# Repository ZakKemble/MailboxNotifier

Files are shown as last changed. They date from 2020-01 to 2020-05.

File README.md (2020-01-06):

Remote Mail Notifier (and GPS tracker)
======================================

A notifier for when mail is received in your mail box! Uses an A9G GPRS/GPS module to send HTTP requests to a web server via the mobile network.\
A PHP script then sends messages to a Telegram group chat using the bot API. Since the A9G also has a built-in GPS receiver the mail notifier can be used as a GPS tracker!\
Also incorporates a BME280 environmental sensor and should last for around 4-5 years on a single charge of a 10440 lithium battery (~320mAh, equivalent AAA size), if mail is received 3 times per week.

[https://blog.zakkemble.net/remote-mail-notifier-and-gps-tracker/](https://blog.zakkemble.net/remote-mail-notifier-and-gps-tracker/)

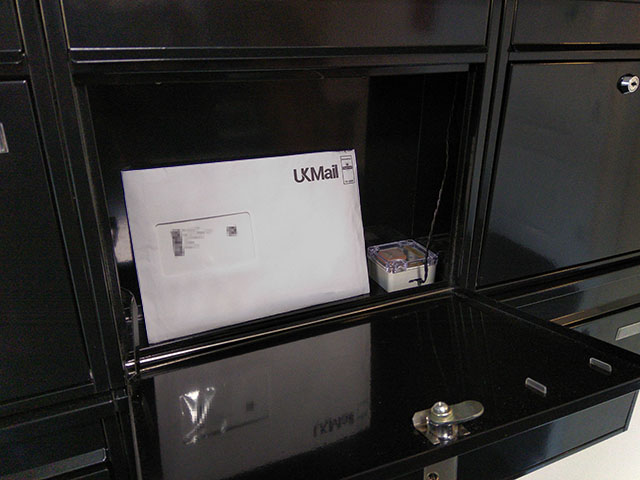
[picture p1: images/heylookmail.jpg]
Mail notifier pic


--------

Zak Kemble

contact@zakkemble.net

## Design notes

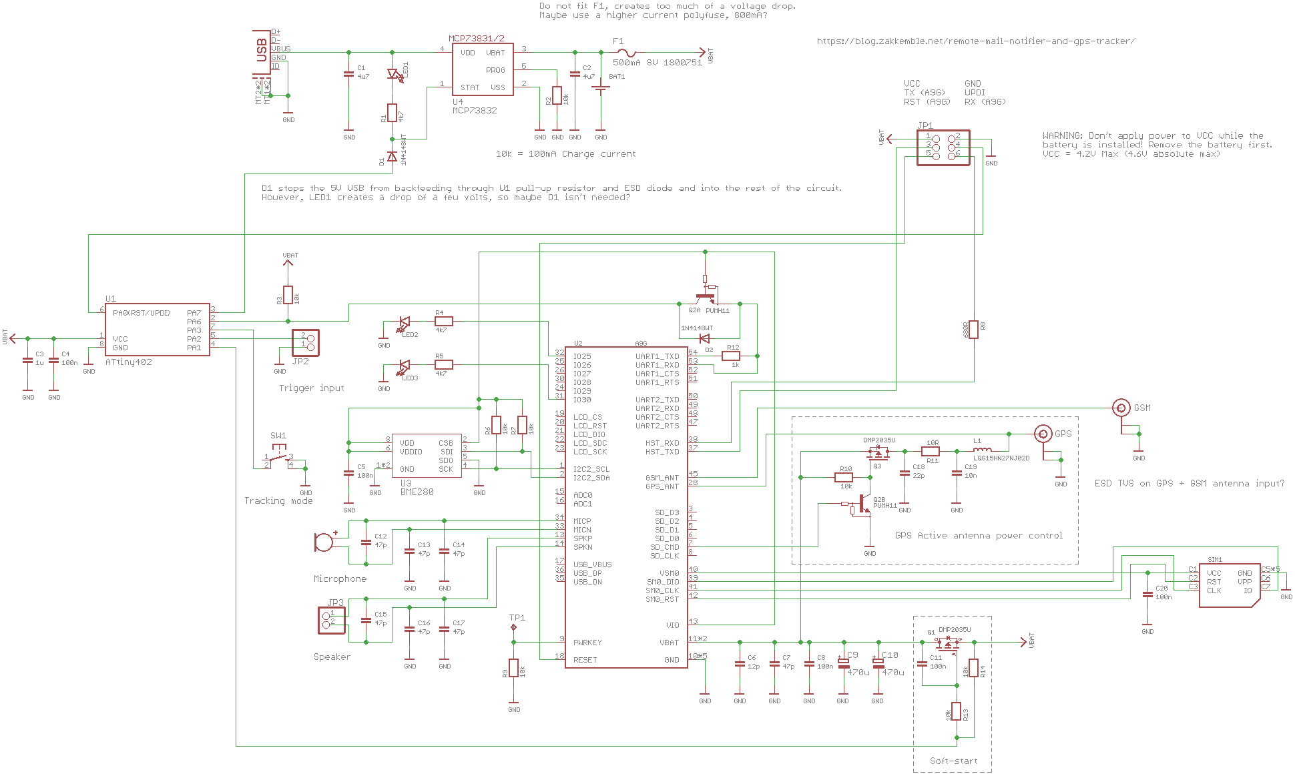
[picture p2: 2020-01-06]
hardware/mailboxNotifier_schematic.png

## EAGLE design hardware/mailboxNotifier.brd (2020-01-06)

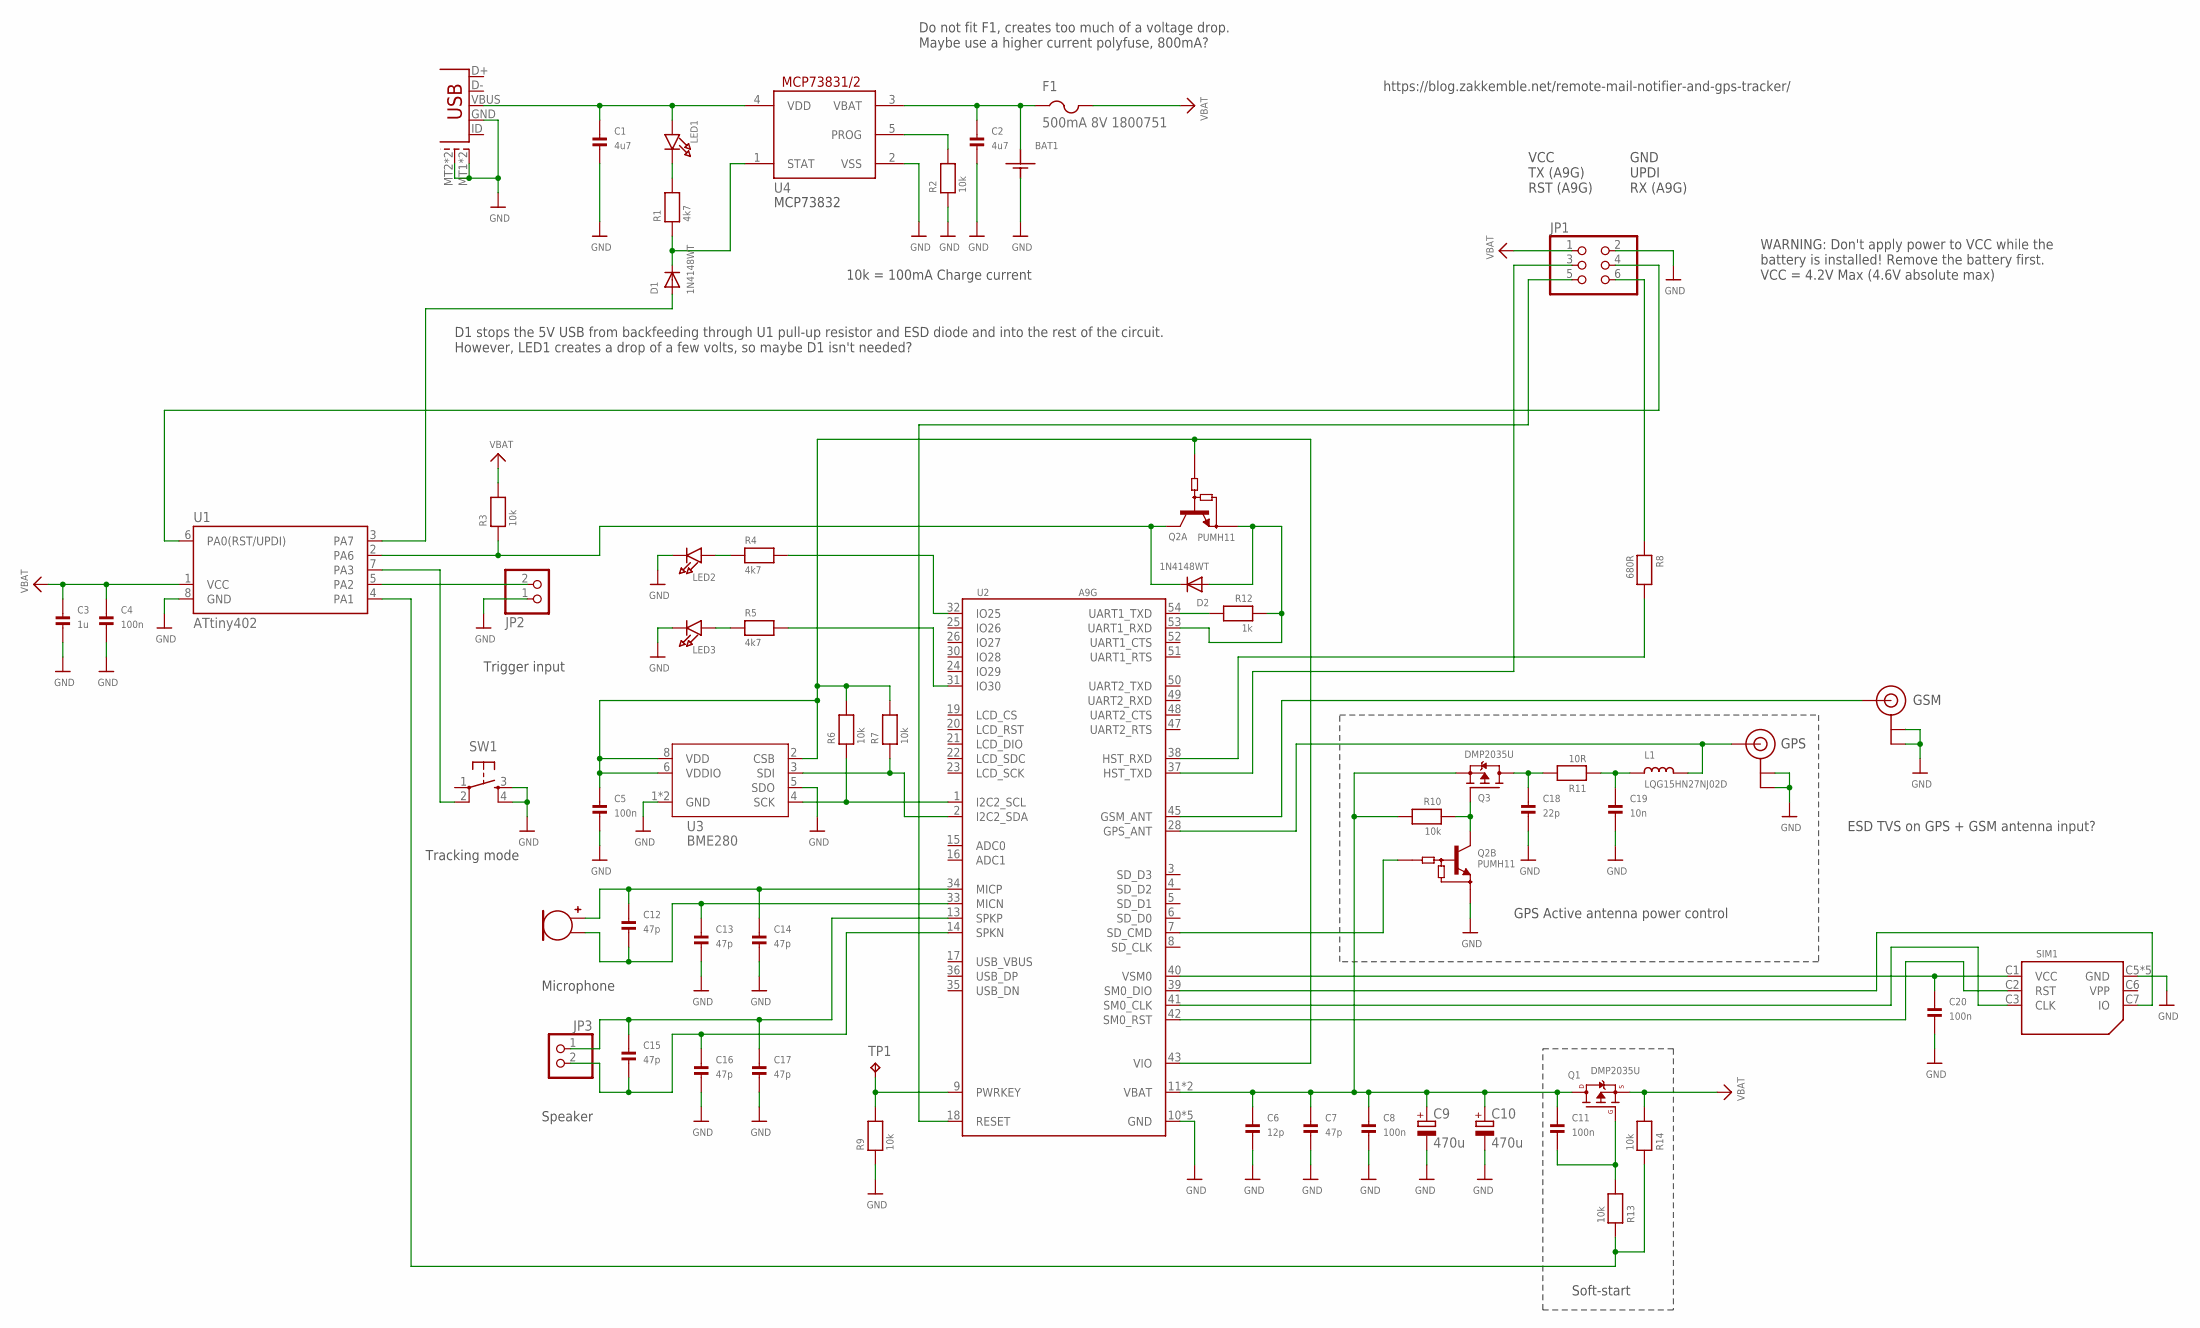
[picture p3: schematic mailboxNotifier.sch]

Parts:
BAT1: BATTERY_HOLDER1XAAA_PCB; BATT_HOLDER_AAA_PCB
C1, C2: 4u7; 0805_NO_OUTLINE
C3: 1u; _0603MP
C4, C5, C8, C11, C20: 100n; 0402_SMALL
C6: 12p; 0402_SMALL
C7, C12, C13, C14, C15, C16, C17: 47p; 0402_SMALL
C9, C10: 470u; E2,5-6
C18: 22p; 0402_SMALL
C19: 10n; 0402_SMALL
D1, D2: 1N4148WT; SOD-523
F1: 500mA 8V 1800751; 1206
JP1: PINHD-2X3; 2X03
JP2: PINHD-1X2/90; 1X02/90
JP3: PINHD-1X2; 1X02
L1: LQG15HN27NJ02D; 0402_SMALL
LED1, LED2, LED3: LED0603_NOOUTLINE; CHIPLED_0603_NOOUTLINE
MIC1: MIC6MM_RA_SWAP
Q1: DMP2035U; SOT-23-WIDE
Q2: PUMH11; SOT-363
Q3: DMP2035U; SOT23-R
R1, R4, R5: 4k7; 0402_SMALL
R2, R3, R6, R7, R9, R10, R13, R14: 10k; 0402_SMALL
R8: 680R; 0402_SMALL
R11: 10R; 0402_SMALL
R12: 1k; 0402_SMALL
SIM1: SIMCARDSOCKET; SIM_SOCKET1
SW1: SPST_TACTG75_3X4; TACT_SMD5
TP1: TPTP10R; TP10R
U1: ATtiny402; SOIC8_150MIL_SMPAD
U2: A9G
U3: BME280
U4: MCP73831/OT; SOT23-5L
U$38, U$55: U.FL
USB1: USB-MICROBSAFEBEE; USB-MICROB_SAFEBEE

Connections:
GND: BAT1.NEG, C1.2, C2.2, C3.2, C4.2, C5.2, C6.2, C7.2, C8.2, C9.-, C10.-, C13.2, C14.2, C16.2, C17.2, C18.2, C19.2, C20.2, JP1.2, JP2.1, LED2.C, LED3.C, Q2.4 (E), R2.1, R9.1, SIM1.C5 (GND), SIM1.GND1 (GND), SIM1.GND2 (GND), SIM1.GND3 (GND), SIM1.GND4 (GND), SW1.3 (S), SW1.4 (S1), U1.8 (GND), U2.10 (GND), U2.27 (GND), U2.29 (GND), U2.44 (GND), U2.46 (GND), U3.1 (GND), U3.5 (SDO), U3.7 (GND), U4.2 (VSS), U$38.1 (GND), U$38.2 (GND), U$55.1 (GND), U$55.2 (GND), USB1.GND, USB1.MT1 (SHEILD1), USB1.MT2 (SHEILD2), USB1.MT3 (SHEILD1), USB1.MT4 (SHEILD2)
unnamed: SIM1.C3 (CLK), U2.41 (SM0_CLK)
unnamed: LED1.C, R1.2
unnamed: SIM1.C2 (RST), U2.42 (SM0_RST)
unnamed: JP1.4, U1.6 (PA0(RST/UPDI))
unnamed: R2.2, U4.5 (PROG)
unnamed: JP1.5, U2.18 (RESET)
unnamed: D2.A, Q2.1 (E), R12.1, U2.53 (UART1_RXD)
unnamed: R12.2, U2.54 (UART1_TXD)
unnamed: D1.A, U1.3 (PA7)
unnamed: D2.K (C), Q2.6 (C), R3.1, U1.2 (PA6)
unnamed: C5.1, Q2.2 (B), R6.2, R7.2, U2.43 (VIO), U3.2 (CSB), U3.6 (VDDIO), U3.8 (VDD)
unnamed: JP2.2, U1.5 (PA2)
unnamed: C20.1, SIM1.C1 (VCC), U2.40 (VSM0)
unnamed: SW1.2 (P1), U1.7 (PA3)
unnamed: R9.2, TP1.TP, U2.9 (PWRKEY)
unnamed: SIM1.C7 (IO), U2.39 (SM0_DIO)
unnamed: Q2.3 (C), Q3.1 (G), R10.1
unnamed: U2.45 (GSM_ANT), U$55.3 (SIGNAL)
unnamed: R4.2, U2.32 (IO25)
unnamed: R6.1, U2.1 (I2C2_SCL), U3.4 (SCK)
unnamed: R5.2, U2.31 (IO30)
unnamed: C12.1, C14.1, MIC1.POS, U2.34 (MICP)
unnamed: Q2.5 (B), U2.7 (SD_CMD)
unnamed: R8.2, U2.38 (HST_RXD)
unnamed: R7.1, U2.2 (I2C2_SDA), U3.3 (SDI)
unnamed: JP1.3, U2.37 (HST_TXD)
unnamed: BAT1.POS, C2.1, F1.1, U4.3 (VBAT)
unnamed: JP1.6, R8.1
unnamed: L1.2, U2.28 (GPS_ANT), U$38.3 (SIGNAL)
unnamed: LED3.A, R5.1
unnamed: C1.1, LED1.A, U4.4 (VDD), USB1.VBUS
unnamed: R13.1, R14.1, U1.4 (PA1)
unnamed: D1.K (C), R1.1, U4.1 (STAT)
unnamed: C18.1, Q3.3 (D), R11.2
unnamed: C19.1, L1.1, R11.1
unnamed: C12.2, C13.1, MIC1.NEG, U2.33 (MICN)
unnamed: C15.1, C17.1, JP3.1, U2.13 (SPKP)
unnamed: LED2.A, R4.1
unnamed: C11.2, Q1.1 (G), R13.2
unnamed: C15.2, C16.1, JP3.2, U2.14 (SPKN)
unnamed: C6.1, C7.1, C8.1, C9.+, C10.+, C11.1, Q1.3 (D), Q3.2 (S), R10.2, U2.11 (VBAT), U2.12 (VBAT)
VBAT: C3.1, C4.1, F1.2, JP1.1, Q1.2 (S), R3.2, R14.2, U1.1 (VCC)

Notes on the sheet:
MCP73832
ESD TVS on GPS + GSM antenna input?
WARNING: Don't apply power to VCC while the battery is installed! Remove the battery first. VCC = 4.2V Max (4.6V absolute max)
VCC TX (A9G) RST (A9G)
GND UPDI RX (A9G)
10k = 100mA Charge current
D1 stops the 5V USB from backfeeding through U1 pull-up resistor and ESD diode and into the rest of the circuit. However, LED1 creates a drop of a few volts, so maybe D1 isn't needed?
Do not fit F1, creates too much of a voltage drop. Maybe use a higher current polyfuse, 800mA?
GPS Active antenna power control
Soft-start
GSM
GPS
Speaker
Microphone
Tracking mode
Trigger input
https://blog.zakkemble.net/remote-mail-notifier-and-gps-tracker/

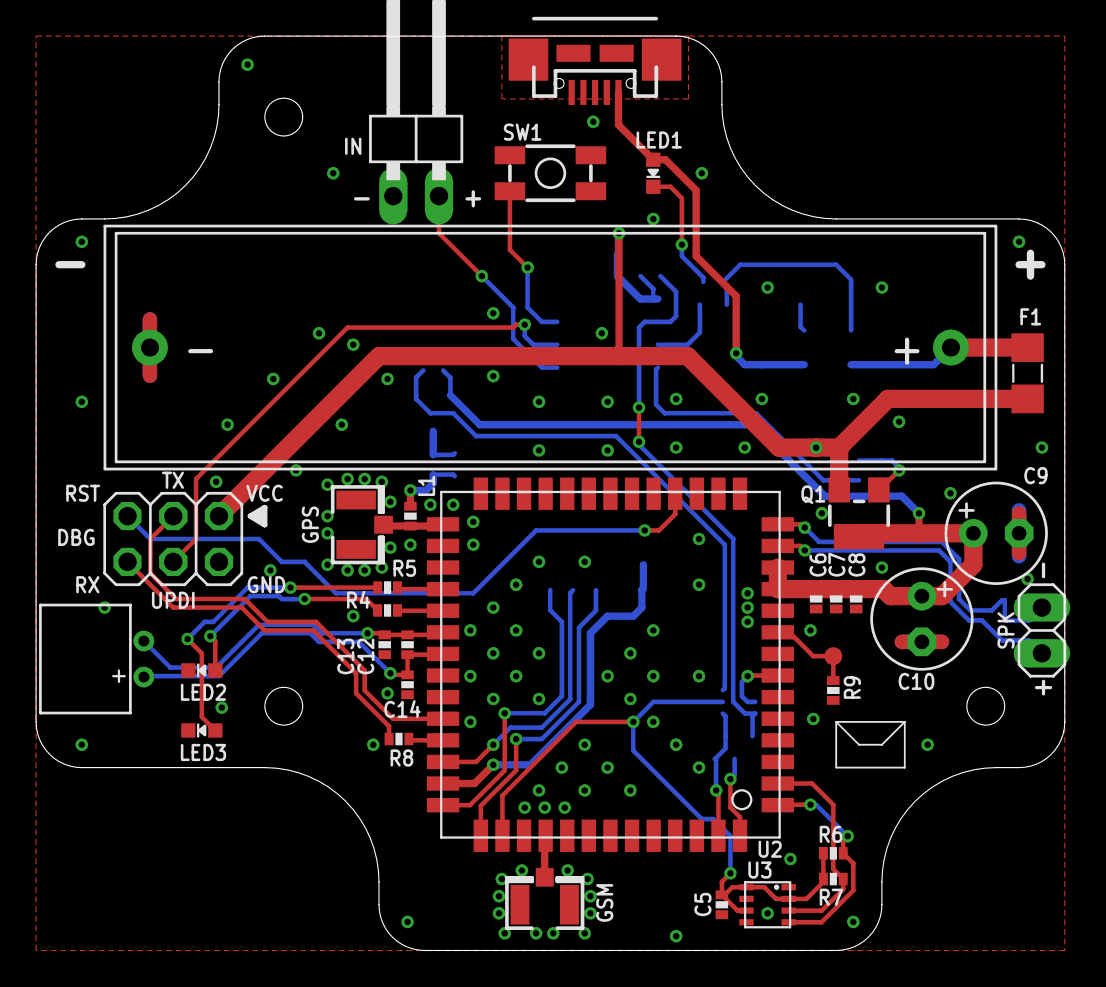
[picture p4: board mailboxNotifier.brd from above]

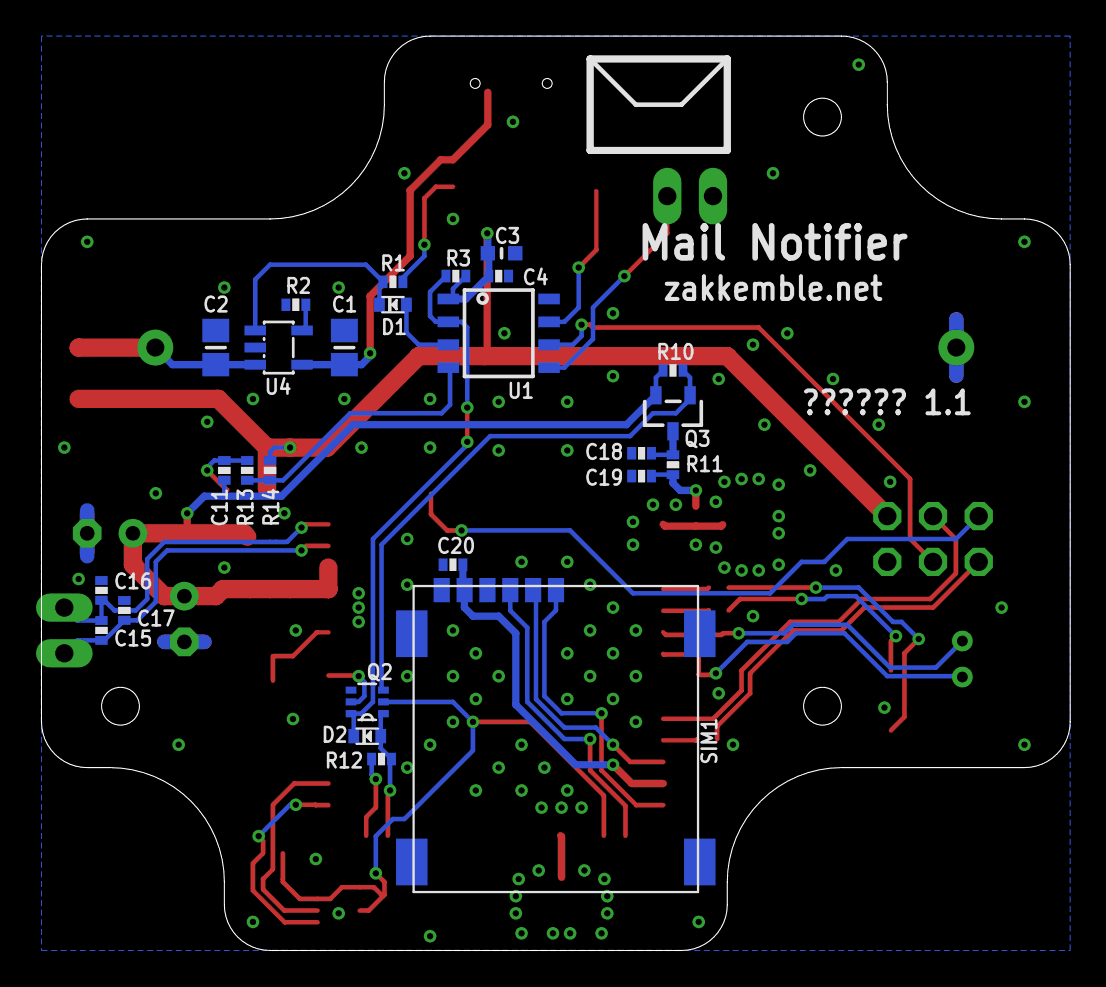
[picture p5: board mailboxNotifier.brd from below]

Board: 2 copper layers, 57.1 x 50.8 mm, 59 parts (26 on the bottom side), 43 nets.

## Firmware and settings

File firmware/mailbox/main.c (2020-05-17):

/*
 * Project: Remote Mail Notifier (and GPS Tracker)
 * Author: Zak Kemble, contact@zakkemble.net
 * Copyright: (C) 2020 by Zak Kemble
 * License: 
 * Web: https://blog.zakkemble.net/remote-mail-notifier-and-gps-tracker/
 */

#include <stdint.h>
#include <stdio.h>
#include <string.h>
#include <limits.h>
#include <avr/io.h>
#include <avr/power.h>
#include <avr/wdt.h>
#include <avr/interrupt.h>
#include <avr/sleep.h>
#include <util/delay.h>
//#include <util/atomic.h>
#include "mailcomm_defs.h"

// A0 = UPDI
// A1 = A9G Power out
// A2 = Trigger switch in
// A3 = Manual switch in
// A6 = UART out
// A7 = Charge detect in

// Fuses:
// WDTCFG: 0x00 (default)
// BODCFG: 0x0C (BOD enabled with wake-up halted until ready)
// OSCCFG: 0x02 (default)
// SYSCFG0: 0xC4 (default)
// SYSCFG1: 0x07 (default)
// APPEND: 0x00 (default)
// BOOTEND: 0x00 (default)
// LOCKBIT: 0x00 (default)

#define BAUDRATE			9600UL

#define VLOWBATT			3500
#define VCHARGEDBATT		4050

#define TIMEOUT				7500 // 2 mins
#define TIMEOUT_KEEPALIVE	3750 // 60 seconds

#define RETRY_COUNT			5



#define VREF_VAL			1100
#define LOWBATT_VAL			(uint8_t)((((float)VREF_VAL / VLOWBATT) * 255.0) + 0.5)
#define CHARGEDBATT_VAL		(uint8_t)((((float)VREF_VAL / VCHARGEDBATT) * 255.0) + 0.5)

#define BAUD_VAL			(uint16_t)((64 * F_CPU) / (16 * BAUDRATE))

#define TMR_MS(ms)			((uint16_t)(((float)ms / 16) + 0.5)) // PIT increments every 16ms

#define STATE_IDLE		0
#define STATE_WAIT		1
#define STATE_POWEROFF	2
#define STATE_DELAY		3

#define CMDDATA_BUFF	8

#define UART_DIR_RX	0
#define UART_DIR_TX	1

#define PWROFF_UNKNOWN	0
#define PWROFF_FAILURE	1
#define PWROFF_SUCCESS	2

typedef enum
{
	TRIG_IDLE = 0,
	TRIG_WAITACTIVE,
	TRIG_ACTIVE,
	TRIG_WAITDEACTIVE,
	TRIG_DISABLE
} trigState_t;

typedef enum
{
	TRIG_CHANGE_NONE = 0,
	TRIG_CHANGE_ACTIVE,
	TRIG_CHANGE_DEACTIVE
} trigChange_t;

typedef struct {
	uint8_t newMail;
	uint8_t trackMode;
	uint8_t switchStuck;
	uint8_t endCharging;
} reasons_t;

typedef struct {
	trigState_t state;
	uint16_t time;
} trigger_t;

static volatile uint16_t now;
static volatile uint8_t interrupt;
static volatile uint8_t uartDirection;
static volatile uint8_t uartData;
static volatile uint8_t uartNewData;

static volatile uint8_t cmdData[CMDDATA_BUFF];
static volatile uint8_t cmdDataIdx;

static volatile uint8_t vlmDetected;

static uint8_t mcusr_mirror __attribute__ ((section(".noinit,\"aw\",@nobits;"))); // BUG: https://github.com/qmk/qmk_firmware/issues/3657

void get_mcusr(void) __attribute__ ((naked, used, section(".init3")));
void get_mcusr()
{
	mcusr_mirror = RSTCTRL.RSTFR;
	RSTCTRL.RSTFR = 0xFF;
}

static trigChange_t trig_process(trigger_t* trig, uint8_t in, uint16_t now)
{
	if(in)
	{
		if(trig->state == TRIG_IDLE)
		{
			trig->state = TRIG_WAITACTIVE;
			trig->time = now;
		}
		else if(trig->state == TRIG_WAITACTIVE && (uint16_t)(now - trig->time) >= 32) // 500ms
		{
			trig->state = TRIG_ACTIVE;
			return TRIG_CHANGE_ACTIVE;
		}
		else if(trig->state == TRIG_WAITDEACTIVE)
			trig->state = TRIG_ACTIVE;
	}
	else if(trig->state != TRIG_IDLE)
	{
		if(trig->state == TRIG_WAITACTIVE)
			trig->state = TRIG_IDLE;
		else if(trig->state == TRIG_ACTIVE)
		{
			trig->state = TRIG_WAITDEACTIVE;
			trig->time = now;
		}
		else if(trig->state == TRIG_WAITDEACTIVE && (uint16_t)(now - trig->time) >= 32) // 500ms
		{
			trig->state = TRIG_IDLE;
			return TRIG_CHANGE_DEACTIVE;
		}
	}
	
	return TRIG_CHANGE_NONE;
}

int main(void)
{
	// TODO Watchdog
	//CCP = CCP_IOREG_gc;
	//WDT.CTRLA = PERIOD_4KCLK_gc; // 4 seconds

	// Brown-out
	//CCP = CCP_IOREG_gc;
	//BOD.CTRLA = BOD_ACTIVE_ENWAKE_gc | BOD_SLEEP_ENABLED_gc; // CCP protected, already set by fuse
	BOD.CTRLB = BOD_LVL_BODLEVEL2_gc; // 2.60V
	BOD.VLMCTRLA = BOD_VLMLVL_25ABOVE_gc; // 3.25V
	BOD.INTCTRL = BOD_VLMIE_bm;

	// Clocks
	// Default clock is 20MHz / 6 = 3.33MHz
	//CCP = CCP_IOREG_gc;
	//CLKCTRL.MCLKCTRLB = CLKCTRL_PDIV_6X_gc | CLKCTRL_PEN_bm;

	// Configure pins
	VPORTA.OUT = PIN1_bm;
	VPORTA.DIR = PIN1_bm;
	PORTA.PIN2CTRL = PORT_PULLUPEN_bm | PORT_ISC_FALLING_gc;
	PORTA.PIN3CTRL = PORT_PULLUPEN_bm | PORT_ISC_BOTHEDGES_gc; // FALLING/RISING interrupt doesn't work in sleep mode for this pin
	PORTA.PIN7CTRL = PORT_PULLUPEN_bm | PORT_ISC_BOTHEDGES_gc;

	// PIT Timer
	RTC.CLKSEL = RTC_CLKSEL0_bm;
	while(RTC.PITSTATUS & RTC_CTRLBUSY_bm);
	RTC.PITINTCTRL = RTC_PI_bm;
	while(RTC.PITSTATUS & RTC_CTRLBUSY_bm);
	RTC.PITCTRLA = RTC_PERIOD1_bm | RTC_PERIOD0_bm | RTC_PITEN_bm; // 16ms
	while(RTC.PITSTATUS & RTC_CTRLBUSY_bm);

	// UART one-wire
	PORTA.PIN6CTRL = PORT_PULLUPEN_bm;
	USART0.BAUD = BAUD_VAL;
	USART0.CTRLA = USART_RXCIE_bm | USART_TXCIE_bm | USART_LBME_bm;
	USART0.CTRLB = USART_RXEN_bm | USART_TXEN_bm | USART_SFDEN_bm | USART_ODME_bm;

	// VREF
	VREF.CTRLA = VREF_ADC0REFSEL_1V1_gc;
	
	// ADC
	ADC0.CTRLA = ADC_RESSEL_8BIT_gc;
	ADC0.CTRLC = ADC_SAMPCAP_bm | ADC_REFSEL_VDDREF_gc | ADC_PRESC_DIV8_gc;
	ADC0.CTRLD = ADC_INITDLY_DLY16_gc;
	ADC0.SAMPCTRL = 8;
	ADC0.MUXPOS = ADC_MUXPOS_INTREF_gc;

	reasons_t reasons = {
		.newMail = 0,
		.trackMode = 0,
		.switchStuck = 0,
		.endCharging = 0
	};

	reasons_t reasonsShadow = {
		.newMail = 0,
		.trackMode = 0,
		.switchStuck = 0,
		.endCharging = 0
	};

	uint16_t successCount = 0;
	uint16_t failureCount = 0;
	uint16_t timeoutCount = 0;
	uint8_t smsBalanceGet = 0;

	trigger_t button = {TRIG_IDLE, 0};
	trigger_t charging = {TRIG_IDLE, 0};
	trigger_t mail = {TRIG_IDLE, 0};

	uint8_t state = STATE_IDLE;

	uint16_t powerOnOffTime = 0;
	uint8_t poweroffDelay = 0;

	uint16_t keepAliveTime = 0;
	
	uint8_t switchStuck = 0;
	uint8_t chargeComplete = 0;

	uint16_t checkStuckTime = 0;
	uint8_t forceCheckStuck = 0;
	
	uint8_t retryCount = 0;
	uint16_t lastRetryTime = 0;
	
	uint8_t clearVlmDetected = 0;

	uartDirection = UART_DIR_RX;

	sei();
	
	while(1)
	{
		cli();
		interrupt = 0;
		uint8_t port = ~VPORTA.IN;
		uint16_t tmpNow = now;
		sei();

		// Button press
		if(trig_process(&button, (port & PIN3_bm), tmpNow) == TRIG_CHANGE_ACTIVE)
		{
			reasons.trackMode = !reasons.trackMode;
			if(!reasons.trackMode)
			{
				powerOnOffTime = tmpNow - TIMEOUT + TMR_MS(15000); // Give 15 seconds to shutdown
				retryCount = RETRY_COUNT;
			}
		}

		// Charge complete
		if(trig_process(&charging, (port & PIN7_bm), tmpNow) == TRIG_CHANGE_DEACTIVE)
		{
			vlmDetected = 0;

			// Only send a charge complete notification once, then wait until the battery voltage drops below VCHARGEDBATT before allowing another notification
			// NOTE: A charge complete notification is sent when charging stops, even if the battery is not full (like from removing USB power)
			if(!chargeComplete)
				reasons.endCharging = 1;
			chargeComplete = 1;
		}

		// Mail trigger
		if(trig_process(&mail, (port & PIN2_bm), tmpNow) == TRIG_CHANGE_ACTIVE)
			reasons.newMail = 1;

		// Mail switch stuck
		if(
			(port & PIN2_bm) &&
			mail.state == TRIG_ACTIVE &&
			(uint16_t)(tmpNow - mail.time) >= TMR_MS(15000) // 15 seconds
		)
		{
			mail.state = TRIG_DISABLE;
			checkStuckTime = tmpNow;
			forceCheckStuck = 0;
			if(!switchStuck)
				reasons.switchStuck = 1;
			switchStuck = 1;
			PORTA.PIN2CTRL &= ~(PORT_PULLUPEN_bm | PORT_ISC_FALLING_gc);
			VPORTA.DIR |= PIN2_bm;
		}

		// Stuck switch stuff
		if(switchStuck && (forceCheckStuck || (uint16_t)(tmpNow - checkStuckTime) >= TMR_MS(2000))) // 2 secs
		{
			checkStuckTime = tmpNow;
			forceCheckStuck = 0;

			PORTA.PIN2CTRL |= PORT_PULLUPEN_bm;
			VPORTA.DIR &= ~PIN2_bm;
			//cli();
			//CCP = CCP_IOREG_gc;
			//CLKCTRL.MCLKCTRLB = CLKCTRL_PDIV_64X_gc | CLKCTRL_PEN_bm;
			// Ideally we would downclock during this delay, but then UART would mess up
			// TODO only do this check when A9G is powered off?
			_delay_us(25);
			//CCP = CCP_IOREG_gc;
			//CLKCTRL.MCLKCTRLB = CLKCTRL_PDIV_6X_gc | CLKCTRL_PEN_bm;
			//sei();
			if(VPORTA.IN & PIN2_bm) // Has pin input gone high? Then the switch has opened and no longer stuck
			{
				reasons.switchStuck = 0;
				switchStuck = 0;
				PORTA.PIN2CTRL |= PORT_ISC_FALLING_gc;
				mail.state = TRIG_IDLE;
			}
			else // Still stuck
			{
				PORTA.PIN2CTRL &= ~PORT_PULLUPEN_bm;
				VPORTA.DIR |= PIN2_bm;
			}
		}
		
		//reasons.newMail = 1;

		switch(state)
		{
			case STATE_DELAY:
			
				// After powring off the GSM module wait for at least 1 second so the capacitors and things discharge before turning it back on
				if(poweroffDelay && (uint16_t)(tmpNow - powerOnOffTime) >= TMR_MS(1000))
				{
					poweroffDelay = 0;
					if(retryCount == 0)
						state = STATE_IDLE;
				}

				// Wait 5 seconds if we're doing a retry
				if(retryCount > 0 && (uint16_t)(tmpNow - lastRetryTime) >= TMR_MS(5000))
				{
					if(!poweroffDelay)
						state = STATE_IDLE;
				}
				
				if(state == STATE_DELAY)
				{
					// Still delaying? Then sleep for 16ms
					// TODO sleep for 1 second instead?
					cli();
					if(!interrupt)
					{
						//BOD.CTRLA = BOD_ACTIVE_ENWAKE_gc | BOD_SLEEP_DIS_gc;
						SLPCTRL.CTRLA = SLPCTRL_SMODE_PDOWN_gc | SLPCTRL_SEN_bm;
						sei();
						sleep_cpu();
						//BOD.CTRLA = BOD_ACTIVE_ENWAKE_gc | BOD_SLEEP_ENABLED_gc;
					}
					sei();
					break;
				}
				__attribute__ ((fallthrough));
			case STATE_IDLE:
				poweroffDelay = 0;
				if(reasons.newMail == 0 && reasons.endCharging == 0 && reasons.trackMode == 0 && reasons.switchStuck == 0) // Nothing to do
				{
					retryCount = 0;

					cli();
					if(!interrupt)
					{
						uint8_t canDoLongSleep = (
							(mail.state == TRIG_IDLE || mail.state == TRIG_DISABLE)
							&& button.state != TRIG_WAITACTIVE
							&& button.state != TRIG_WAITDEACTIVE
							&& charging.state != TRIG_WAITACTIVE
							&& charging.state != TRIG_WAITDEACTIVE
						);
						
						// Long sleep:
						// Infinite if everything is ok (wake up by pin change interrupt)
						// 32 seconds if switch is stuck (to see if its still stuck)

						if(canDoLongSleep)
						{
							if(!switchStuck)
								RTC.PITCTRLA = 0; // PIT off
							else
								RTC.PITCTRLA = RTC_PERIOD3_bm | RTC_PERIOD2_bm | RTC_PERIOD1_bm | RTC_PITEN_bm; // 32 seconds

							// RTC/PIT update takes around 3ms to complete
							// Downclock CPU to save power
							CCP = CCP_IOREG_gc;
							CLKCTRL.MCLKCTRLB = CLKCTRL_PDIV_64X_gc | CLKCTRL_PEN_bm;
							while(RTC.PITSTATUS & RTC_CTRLBUSY_bm);
							CCP = CCP_IOREG_gc;
							CLKCTRL.MCLKCTRLB = CLKCTRL_PDIV_6X_gc | CLKCTRL_PEN_bm;
						}

						//BOD.CTRLA = BOD_ACTIVE_ENWAKE_gc | BOD_SLEEP_DIS_gc;
						SLPCTRL.CTRLA = SLPCTRL_SMODE_PDOWN_gc | SLPCTRL_SEN_bm;
						sei();
						sleep_cpu();
						//BOD.CTRLA = BOD_ACTIVE_ENWAKE_gc | BOD_SLEEP_ENABLED_gc;

						// Put PIT back to 16ms
						if(canDoLongSleep)
						{
							RTC.PITCTRLA = RTC_PERIOD1_bm | RTC_PERIOD0_bm | RTC_PITEN_bm; // 16ms

							cli();
							CCP = CCP_IOREG_gc;
							CLKCTRL.MCLKCTRLB = CLKCTRL_PDIV_64X_gc | CLKCTRL_PEN_bm;
							sei();
							while(RTC.PITSTATUS & RTC_CTRLBUSY_bm);
							cli();
							CCP = CCP_IOREG_gc;
							CLKCTRL.MCLKCTRLB = CLKCTRL_PDIV_6X_gc | CLKCTRL_PEN_bm;
							sei();
						}

						// The stuck switch timer counter expects the timer to increment every 16ms, but we
						// might have just woken up from a 32 second PIT, so set forceCheckStuck to make it check now
						forceCheckStuck = 1;
					}
					sei();
					break;
				}
				else // We have something to do
				{
					// Check battery voltage
					ADC0.CTRLA |= ADC_ENABLE_bm;
					ADC0.COMMAND = ADC_STCONV_bm;
					while(ADC0.COMMAND); // ~100us
					uint8_t val = ADC0.RESL;
					ADC0.CTRLA &= ~ADC_ENABLE_bm;

					// TODO?
					// Do we need to discard the first conversion after starting the ADC?
					// The ADC has an initialization delay thing which is supposed to let everything settle.
					
					// Remember, reverse logic with these val compares

					// If battery voltage falls below VCHARGEDBATT then the battery is no longer considered fully charged.
					// This will allow a charge complete notification next time charging stops.
					if(val > CHARGEDBATT_VAL)
						chargeComplete = 0;

					if(val < LOWBATT_VAL)
					{
						// Battery is good, turn on GSM module
						if(!vlmDetected)
							clearVlmDetected = 1;
						VPORTA.OUT &= ~PIN1_bm;
						powerOnOffTime = tmpNow;
						keepAliveTime = tmpNow;
						uartNewData = 0;
						state = STATE_WAIT;
						reasonsShadow.newMail = 0;
						reasonsShadow.endCharging = 0;
						//reasonsShadow.trackMode = 0;
						reasonsShadow.switchStuck = 0;
					}
					else
					{
						// Battery too low, clear everything and do nothing
						reasons.newMail = 0;
						reasons.endCharging = 0;
						reasons.trackMode = 0;
						reasons.switchStuck = 0;
						retryCount = 0;
						break;
					}
				}
				__attribute__ ((fallthrough));
			case STATE_WAIT:
				if(!reasons.trackMode && (uint16_t)(tmpNow - powerOnOffTime) >= TIMEOUT)// || (uint16_t)(tmpNow - keepAliveTime) > TIMEOUT_KEEPALIVE) // TODO implement keep-alive stuff
				{
					// Module is taking too long doing stuff, force turn off and retry

					VPORTA.OUT |= PIN1_bm;
					if(timeoutCount < UINT_MAX)
						timeoutCount++;
					
					retryCount++;
					if(retryCount < RETRY_COUNT)
					{
						reasons.newMail |= reasonsShadow.newMail;
						reasons.endCharging |= reasonsShadow.endCharging;
						//reasons.trackMode |= reasonsShadow.trackMode;
						reasons.switchStuck |= reasonsShadow.switchStuck;
					}
					else
					{
						// Tried too many times, clear everything and do nothing
						retryCount = 0;
						reasons.newMail = 0;
						reasons.endCharging = 0;
						//reasons.trackMode = 0;
						reasons.switchStuck = 0;
					}
					lastRetryTime = tmpNow;
					
					state = STATE_POWEROFF;
				}
				else
				{
					cli();
					if(!uartNewData && !interrupt)
					{
						if(uartDirection == UART_DIR_TX)// Idle sleep and wait for UART TX complete interrupt or PIT interrupt
							SLPCTRL.CTRLA = SLPCTRL_SMODE_IDLE_gc | SLPCTRL_SEN_bm;
						else // Standby sleep and wait for UART data or PIT interrupt
							SLPCTRL.CTRLA = SLPCTRL_SMODE_STDBY_gc | SLPCTRL_SEN_bm;

						sei();
						sleep_cpu();
					}
					sei();
					
					// When the A9G is first turned on the inrush current to all the capacitors causes the battery voltage to drop by around 0.8V, even with a soft-start thing in place.
					// This might trigger the VLM thing, so clear it after ~500ms if it wasn't already set before powering on.
					// Maybe I should make the soft-start even more fluffy u.u
					if(clearVlmDetected && (uint16_t)(tmpNow - powerOnOffTime) >= TMR_MS(480))
					{
						vlmDetected = 0;
						clearVlmDetected = 0;
					}

					// Commands processor
					if(uartNewData)
					{
						cli();
						uint8_t data = uartData;
						uartNewData = 0;
						sei();

						uint8_t cmd = data & 0x07;
						data >>= 3;

						//if(state == STATE_WAIT)// && uartDirection == UART_DIR_RX)
						switch(cmd)
						{
							case MAIL_COMM_REQUEST:
								cmdData[0] = MAIL_COMM_DO;
								cmdData[1] = successCount>>8;
								cmdData[2] = successCount;
								cmdData[3] = failureCount>>8;
								cmdData[4] = failureCount;
								cmdData[5] = timeoutCount>>8;
								cmdData[6] = timeoutCount;
								cmdData[7] = (smsBalanceGet == 0)<<5 | vlmDetected<<4 | reasons.newMail<<3 | reasons.endCharging<<2 | reasons.trackMode<<1 | reasons.switchStuck;
								cmdDataIdx = 0;
								USART0.CTRLA |= USART_DREIE_bm;
								reasonsShadow.newMail = reasons.newMail;
								reasonsShadow.endCharging = reasons.endCharging;
								//reasonsShadow.trackMode = reasons.trackMode;
								reasonsShadow.switchStuck = reasons.switchStuck;
								reasons.newMail = 0;
								reasons.endCharging = 0;
								//reasons.trackMode = 0;
								reasons.switchStuck = 0;
								//break;
								__attribute__ ((fallthrough));
							case MAIL_COMM_KEEPALIVE:
								keepAliveTime = tmpNow;
								break;
							case MAIL_COMM_POWEROFF:
								if(data == PWROFF_SUCCESS)
								{
									if(successCount < UINT16_MAX)
										successCount++;

									// Only get balance once every 10 wakes
									// This saves ~8 seconds, increasing battery life
									smsBalanceGet++;
									if(smsBalanceGet >= 10)
										smsBalanceGet = 0;

									retryCount = 0;
								}
								else
								{
									if(failureCount < UINT16_MAX)
										failureCount++;

									if(!reasons.trackMode) // Retry forever if in tracking mode
										retryCount++;

									if(retryCount < RETRY_COUNT)
									{
										reasons.newMail |= reasonsShadow.newMail;
										reasons.endCharging |= reasonsShadow.endCharging;
										//reasons.trackMode |= reasonsShadow.trackMode;
										reasons.switchStuck |= reasonsShadow.switchStuck;
									}
									else
									{
										// Tried too many times, clear everything and do nothing
										retryCount = 0;
										reasons.newMail = 0;
										reasons.endCharging = 0;
										//reasons.trackMode = 0;
										reasons.switchStuck = 0;
									}
									lastRetryTime = tmpNow;
								}
								state = STATE_POWEROFF;
								break;
							default:
								memset((uint8_t*)cmdData, '?', CMDDATA_BUFF);
								cmdData[1] = cmd;
								cmdData[2] = data;
								cmdDataIdx = 0;
								USART0.CTRLA |= USART_DREIE_bm;
								break;
						}
					}
				}
				break;
			case STATE_POWEROFF:
				VPORTA.OUT |= PIN1_bm;
				state = STATE_DELAY;
				poweroffDelay = 1;
				powerOnOffTime = tmpNow;
				break;
			default:
				break;
		}

		wdt_reset();
	}
}

ISR(PORTA_PORT_vect)
{
	VPORTA.INTFLAGS = PORT_INT7_bm | PORT_INT3_bm | PORT_INT2_bm;
	interrupt = 1;
}

ISR(USART0_RXC_vect)
{
	uint8_t data = USART0.RXDATAL;
	if(uartDirection == UART_DIR_RX)
	{
		uartData = data;
		uartNewData = 1;
	}
}

ISR(USART0_TXC_vect)
{
	USART0.STATUS = USART_TXCIF_bm; // NOTE: This is not automatically cleared in loopback/one-wire mode!
	if(cmdDataIdx >= CMDDATA_BUFF)
	{
		uartDirection = UART_DIR_RX;
	}
}

ISR(USART0_DRE_vect)
{
	if(cmdDataIdx < CMDDATA_BUFF)
	{
		uartDirection = UART_DIR_TX;
		USART0.TXDATAL = cmdData[cmdDataIdx];
		cmdDataIdx++;

		if(cmdDataIdx >= CMDDATA_BUFF)
			USART0.CTRLA &= ~USART_DREIE_bm;
	}
	//else
	//	USART0.CTRLA &= ~USART_DREIE_bm;
}

ISR(RTC_PIT_vect)
{
	RTC.PITINTFLAGS = RTC_PI_bm;
	++now;
	interrupt = 1;
}

ISR(BOD_VLM_vect)
{
	BOD.INTFLAGS = BOD_VLMIF_bm;
	vlmDetected = 1;
}

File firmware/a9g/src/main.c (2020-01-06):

/*
 * Project: Remote Mail Notifier (and GPS Tracker)
 * Author: Zak Kemble, contact@zakkemble.net
 * Copyright: (C) 2020 by Zak Kemble
 * License: 
 * Web: https://blog.zakkemble.net/remote-mail-notifier-and-gps-tracker/
 */

#include "common.h"

#define MAIN_TASK_STACK_SIZE    (1024 * 2)
#define MAIN_TASK_PRIORITY      0 
#define MAIN_TASK_NAME         "Main task"

#define MAILBOX_TASK_STACK_SIZE    (1024 * 2)
#define MAILBOX_TASK_PRIORITY      1
#define MAILBOX_TASK_NAME         "Mail box task"

static HANDLE mainTaskHandle = NULL;
static HANDLE mailboxTaskHandle = NULL;
extern char* fwBuild;
static Power_On_Cause_t pwrOnCause;

void EventDispatch(API_Event_t* pEvent)
{
    switch(pEvent->id)
    {
		case API_EVENT_ID_POWER_ON:
			pwrOnCause = pEvent->param1;
			break;
        case API_EVENT_ID_SYSTEM_READY:
			PRINTD("FW: " FW_VERSION " (Built: %s)", fwBuild);
			PRINTD("system initialize complete (%u)", pwrOnCause);
			sms_info();
			mail_sendEvent(MAILBOX_EVT_BEGIN, 0, 0, NULL, NULL);
            break;
		case API_EVENT_ID_NO_SIMCARD:
			PRINTD("!!NO SIM CARD %d!!!!", pEvent->param1);
			// TODO turn off
			break;
		case API_EVENT_ID_SIMCARD_DROP:
			PRINTD("!!SIM CARD DROP %d!!!!", pEvent->param1);
			// TODO what now?
			break;
		case API_EVENT_ID_KEY_DOWN:
			break;
		case API_EVENT_ID_KEY_UP:
			break;
		case API_EVENT_ID_MALLOC_FAILED:
			PRINTD("MALLOC FAILED");
			break;
		case API_EVENT_ID_POWER_INFO:
			break;
		case API_EVENT_ID_USSD_IND:
		case API_EVENT_ID_USSD_SEND_SUCCESS:
		case API_EVENT_ID_USSD_SEND_FAIL:
			break;
        default:
			mailbox_eventDispatch(pEvent);
//			PRINTD("EVT2 %d %d %d", pEvent->id, pEvent->param1, pEvent->param2);
            break;
    }
}

static void unusedGPIO(GPIO_PIN pin)
{
	GPIO_EnablePower(pin, true);
	GPIO_config_t gpioUnused = {
		.mode			= GPIO_MODE_OUTPUT,
		.pin			= pin,
		.defaultLevel	= GPIO_LEVEL_LOW
	};
	if(!GPIO_Init(gpioUnused))
		PRINTD("GPIO CONFIG FAIL %u", pin);
}

static GPIO_PIN unused[] = {
	// VPAD1
	GPIO_PIN2,
	GPIO_PIN3,
	GPIO_PIN6,
	GPIO_PIN7,
	// MMC
	GPIO_PIN8,
	GPIO_PIN10,
	GPIO_PIN11,
	GPIO_PIN12,
	GPIO_PIN13,
	// LCD
	GPIO_PIN14,
	GPIO_PIN15,
	GPIO_PIN16,
	GPIO_PIN17,
	GPIO_PIN18,
	// CAM
	GPIO_PIN19,
	GPIO_PIN20,
	GPIO_PIN21,
	GPIO_PIN22,
	GPIO_PIN23,
	GPIO_PIN24,
	// VPAD2
	GPIO_PIN26,
	GPIO_PIN27,
	GPIO_PIN28,
	GPIO_PIN29,
	GPIO_PIN31, // Keep OUTPUT LOW to reduce current
	GPIO_PIN32, // Keep OUTPUT LOW to reduce current
	GPIO_PIN33, // Keep OUTPUT LOW to reduce current
	GPIO_PIN34, // Keep OUTPUT LOW to reduce current
};

static void init(void)
{
	PM_SetSysMinFreq(PM_SYS_FREQ_13M);

	for(uint8_t i=0;i<sizeof(unused)/sizeof(GPIO_PIN);i++)
		unusedGPIO(unused[i]);

	led_init();

	// GPS antenna power
	GPIO_EnablePower(GPIO_PIN9, true);
	GPIO_config_t gpioGPSAntennaPower = {
		.mode			= GPIO_MODE_OUTPUT,
		.pin			= GPIO_PIN9,
		.defaultLevel	= GPIO_LEVEL_LOW
	};
	GPIO_Init(gpioGPSAntennaPower);

	// BME280
	PM_PowerEnable(POWER_TYPE_CAM, true);
    I2C_Config_t i2cConfig;
    i2cConfig.freq = I2C_FREQ_100K;
    I2C_Init(I2C2, i2cConfig);

	TIME_SetIsAutoUpdateRtcTime(true);
	gsm_init();
	gprs_init();
	sms_init();
	bme280_init();
	mailcomm_init();
}

void MainTask(void *pData)
{
	init();

	mailboxTaskHandle = OS_CreateTask(
		mailbox_task,
		&mailboxTaskHandle,
		NULL,
		MAILBOX_TASK_STACK_SIZE,
		MAILBOX_TASK_PRIORITY,
		0,
		0,
		MAILBOX_TASK_NAME
	);

	API_Event_t* event = NULL;
	while(1)
	{
		if(OS_WaitEvent(mainTaskHandle, (void**)&event, OS_TIME_OUT_WAIT_FOREVER))
		{
			EventDispatch(event);
			OS_Free(event->pParam1);
			OS_Free(event->pParam2);
			OS_Free(event);
		}
	}
}

void mailbox_Main()
{
    mainTaskHandle = OS_CreateTask(
		MainTask,
        NULL,
		NULL,
		MAIN_TASK_STACK_SIZE,
		MAIN_TASK_PRIORITY,
		0,
		0,
		MAIN_TASK_NAME
	);
    OS_SetUserMainHandle(&mainTaskHandle);
}

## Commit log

2020-01-06 Initial commit :hurtrealbad:
    [mailboxNotifier.brd, mailboxNotifier.sch]
2020-05-17 Fixes and tweaks
    Various fixes and tweaks, like default clock source is 20MHz, not 16MHz!
    [main.c]

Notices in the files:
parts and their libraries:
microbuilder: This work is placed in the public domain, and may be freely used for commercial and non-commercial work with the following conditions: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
